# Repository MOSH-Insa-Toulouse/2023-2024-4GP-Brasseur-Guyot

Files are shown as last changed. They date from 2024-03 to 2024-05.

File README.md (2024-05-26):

# 2023-2024-4GP-Brasseur-Guyot

Projet capteur low-tech en graphite par Damien Brasseur et Tristan Guyot : le **BG0524-LTG**

### Contexte

Ce capteur a été réalisé, instrumenté et caractérisé dans le cadre d'un projet de 4ème année au département du Génie Physique de l'INSA TOULOUSE, encadré par Jérémie Grisolia, Benjamin Mestre, Arnaud Biganzoli et Cathy Crouzet. Tout le code, schématiques et mesures sont *open source* et réutilisables à volonté.

### Contacts

Damien : brasseu@insa-toulouse.fr <br>
Tristan : tguyot@insa-toulouse.fr

### Table des matières

[Description générale du projet](#coo) <br>
[Caractéristiques techniques](#zozo) <br>
[Mode d'emploi](#pookie) <br>
[Tests du capteur graphite](#booboo)

## 1 - Description générale du projet <a name="coo">

### Principe

Les capteurs sont partout. Dès qu’on cherche à automatiser un système, quel qu’il soit, on a besoin de capteurs. Pourtant, la plupart sont très coûteux en énergie, et leur multiplication fait qu’ils sont de plus en plus impactants sur l’environnement. C’est pour ça que les capteurs low-tech représentent un atout non négligeable. 

Un dépôt de graphite sur du papier forme un système granulaire, composé de grains de plus ou moins grande taille espacés d'une certaine distance, appelée distance inter-grain.
Cette propriété fait que sa conductance dépend de façon exponentielle de la distance inter-grain, qui peut être modulée en repliant le papier.
Ainsi, on peut retrouver la contrainte appliquée au matériau directement en mesurant la résistance aux bornes du capteur.

### Contenu du banc

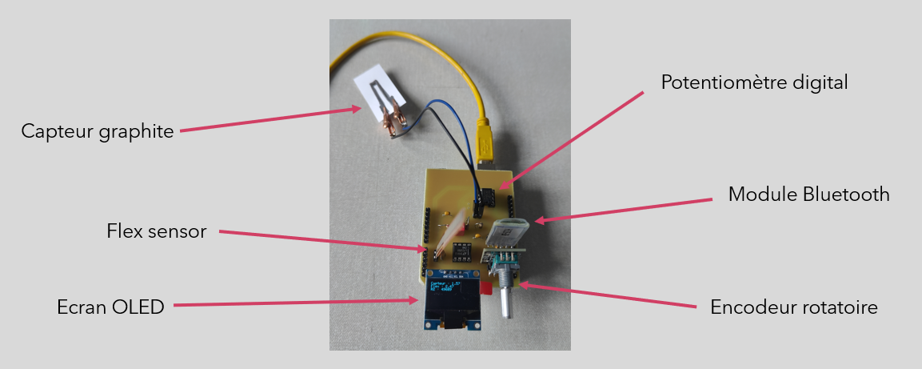
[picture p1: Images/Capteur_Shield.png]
Le projet dans son ensemble
 <br>

 - Le capteur graphite (interchangeable)
 - Un amplificateur permettant de mesurer avec précision les variations (cette amplification peut être modulée via la modification de la résistance R2 de la boucle de rétroaction de l'amplificateur, pilotée grâce à l'encodeur rotatoire)
 - Un capteur flex-sensor permettant de comparer les mesures du capteur graphite
 - Un écran OLED, sur lequel les mesures sont affichées en temps-réel
 - Une application Android, connectée en Bluetooth, sur laquelle les mesures et leur variation peuvent être visionnée

## 2 - Caractéristiques techniques <a name="zozo">

La *datasheet* est accessible [ici](./Datasheet/datasheet_capteur-graphite_final.pdf)

### Capteur

Le capteur est constitué d'une feuille de papier recouverte de graphite déposé au crayon selon un patterne spécifique :

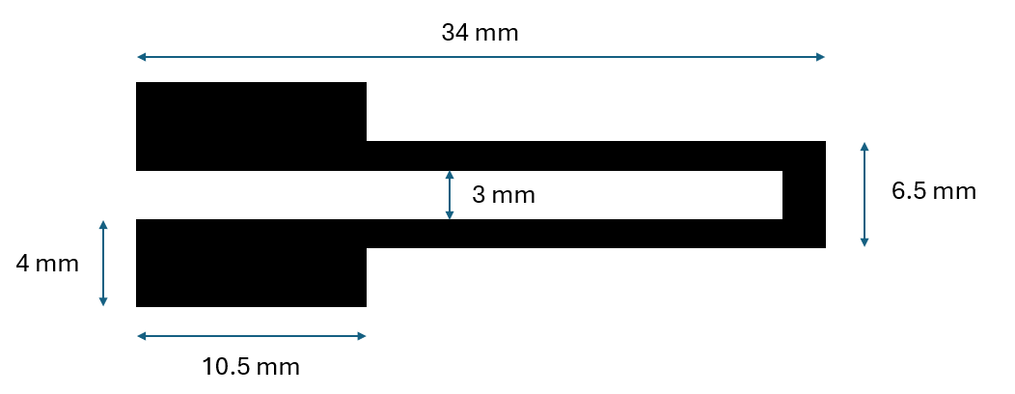
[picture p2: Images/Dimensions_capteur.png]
Le capteur graphite
 <br>

L'épaisseur du papier utilisé est de 200 µm.

### Electronique

L'électronique analogique permettant d'amplifier et de filtrer le signal du capteur graphite est composé d'un amplificateur transimpédance LTC1050 et de trois filtres :
 - Un filtre passif en entrée permettant d'éviter la distortion dans l'étage d'entrée
 - Un filtre actif basé sur l'amplificateur permettant une efficacité maximale
 - Un filtre passif en sortie pour éliminer le bruit introduit lors du traitement.

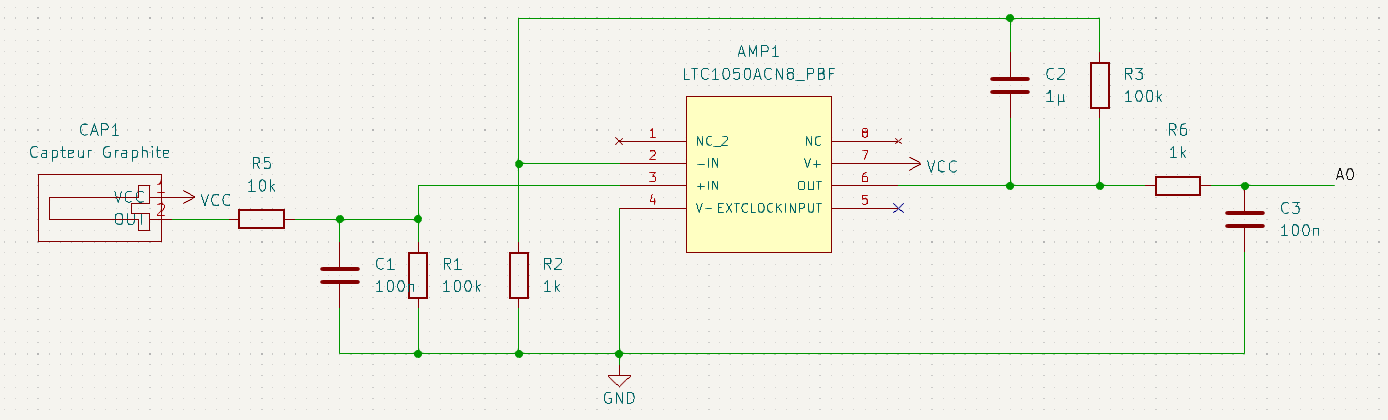
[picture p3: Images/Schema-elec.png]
Schéma de l'amplification
 <br>

### KiCad

Explications disponibles [ici](https://github.com/MOSH-Insa-Toulouse/2023-2024-4GP-Brasseur-Guyot/tree/main/KiCad)

### Code Arduino

Explications disponibles [ici](https://github.com/MOSH-Insa-Toulouse/2023-2024-4GP-Brasseur-Guyot/tree/main/Code%20Arduino)

### Application Android

Explications disponibles [ici](https://github.com/MOSH-Insa-Toulouse/2023-2024-4GP-Brasseur-Guyot/tree/main/Application%20Android)

## 3 - Mode d'emploi <a name="pookie">

### KiCad

Le dossier KiCad est à télécharger dans son intégralité.
Une fois téléchargé, il faudra recharger les librairies de symboles depuis le dossier Mods.

### Code Arduino

Pour charger le code sur la carte **Arduino UNO**, rien de plus facile ! Il suffit de l'ouvrir dans l'application Arduino IDE avec la carte branchée en USB, puis cliquer sur *Upload*.

### Application Android

L'application est à télécharger sur un téléphone Android. Après l'installation, aller dans les paramètres des applications Android et accorder l'accès au Bluetooth et au micro à l'application.
Pour assurer la connexion entre la carte Arduino et le téléphone, il faut d'abord se connecter au module Bluetooth de la carte avec l'interface générale Bluetooth du téléphone. Ensuite, on pourra sélectionner dans l'application le module et on pourra commencer à s'amuser.

## 4 - Tests du capteur graphite <a name="booboo">

Nous avons réalisé des mesures de compression et de détente avec des capteurs comportant différentes densités de graphite (variant avec le type de crayon : 4H, HB et 4B), ainsi que pour le Flex sensor.

Le banc de test sur lequel nous avons testé les mesures comporte 4 demi-cercles de diamètres 2cm, 3cm, 4cm et 5cm, respectivement. La déformation est calculée selon l'expression suivante : $\varepsilon = \frac{D}{e}$ avec $D$ diamètre du demi-cercle et $e$ épaisseur du papier.

Voici la caractéristique en détente : 

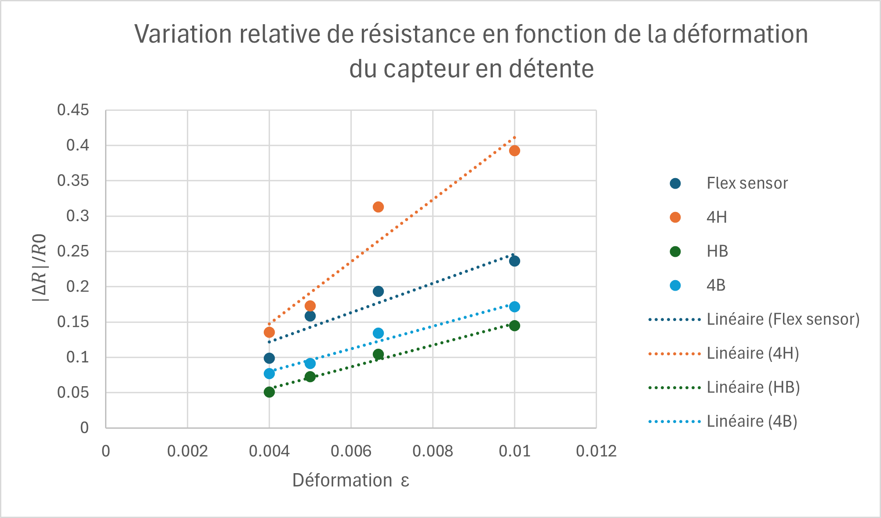
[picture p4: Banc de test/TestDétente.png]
Caractéristique en détente
 <br>

On remarque que la variation de résistance la plus marquée (pente la plus élevée) est cele du capteur au crayon 4H. De façon surprenante, le capteur au cayon HB est moins efficace que le capteur 4B.

Voici la caractéristique en compression : 

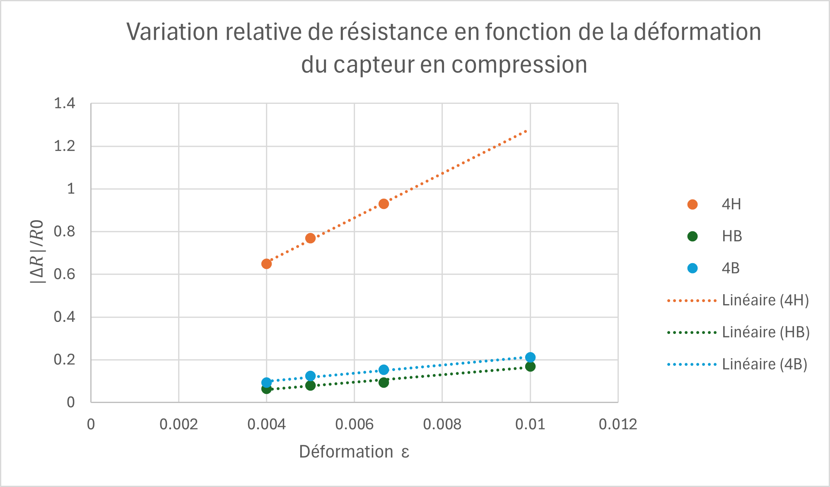
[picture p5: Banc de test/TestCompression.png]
Caractéristique en compression
 <br>

Même comportement, sauf qu'une limite a été atteinte en mesure de compression (demi-cercle de 2cm) avec le capteur 4H. Le flex sensor ne fonctionnant que dans un seul sens, nous n'avons pas pu le tester dans ces conditions.

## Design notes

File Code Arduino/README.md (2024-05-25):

# Code Arduino

Ce code permet de réaliser l'interface entre les capteurs, le potentiomètre permettant de régler l'amplification, l'écran OLED et la connexion Bluetooth au téléphone.

Boucle de 50ms : 
 - Récupération des valeurs analogiques de tension du capteur graphite et du flex sensor
 - Réglage de la résistance R2 de l'amplification avec l'encodeur rotatoire
 - Affichage des valeurs de tension sur l'écran OLED
 - Envoi des valeurs de tension au module Bluetooth (1 fois sur 10 => toutes les 500ms)

### capteur_graphite.ino

C'est le code à envoyer sur la carte Arduino UNO pour faire fonctionner le banc.

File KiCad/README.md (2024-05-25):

# Shield KiCad

Modèle du PCB par lequel les différents éléments du projet sont reliés, réalisé sur **KiCad** :

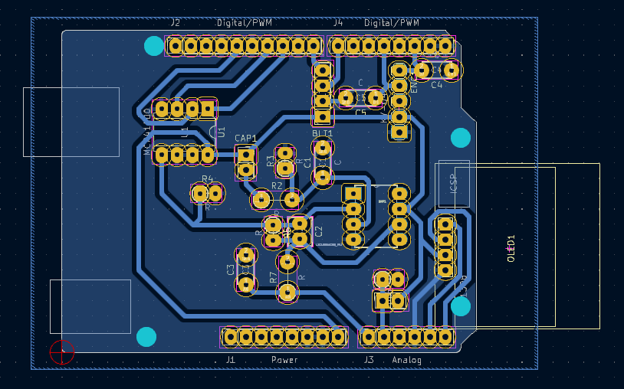
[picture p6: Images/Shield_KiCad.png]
Shield KiCad
 <br>

Principales caractéristiques :
 - Tous les circuits sur une seule face
 - Tous les composants directement intégrés au PCB
 - Pins non reliés : au GND

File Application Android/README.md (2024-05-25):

# Application Android

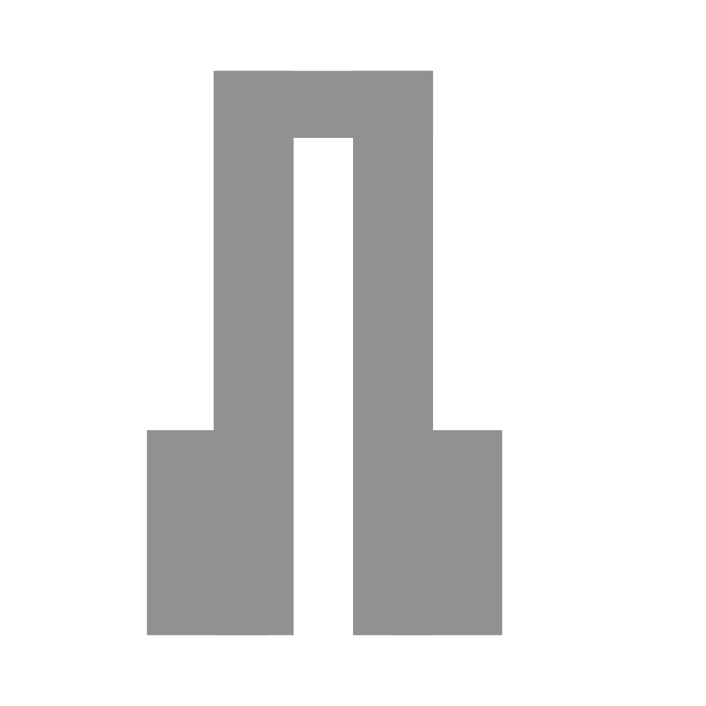
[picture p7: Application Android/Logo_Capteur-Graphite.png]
Logo App Capteur
 <br>

## Description de l'application

Cette application, réalisée à l'aide du MIT App Inventor, permet de se connecter en Bluetooth à la carte Arduino faisant tourner le capteur, et récupérer les mesures à la fois du capteur graphite et du flex sensor. 
Ensuite, un graphe permet de visualiser la variation en temps-réel de ces mesures, soit simultanément ou séparément.

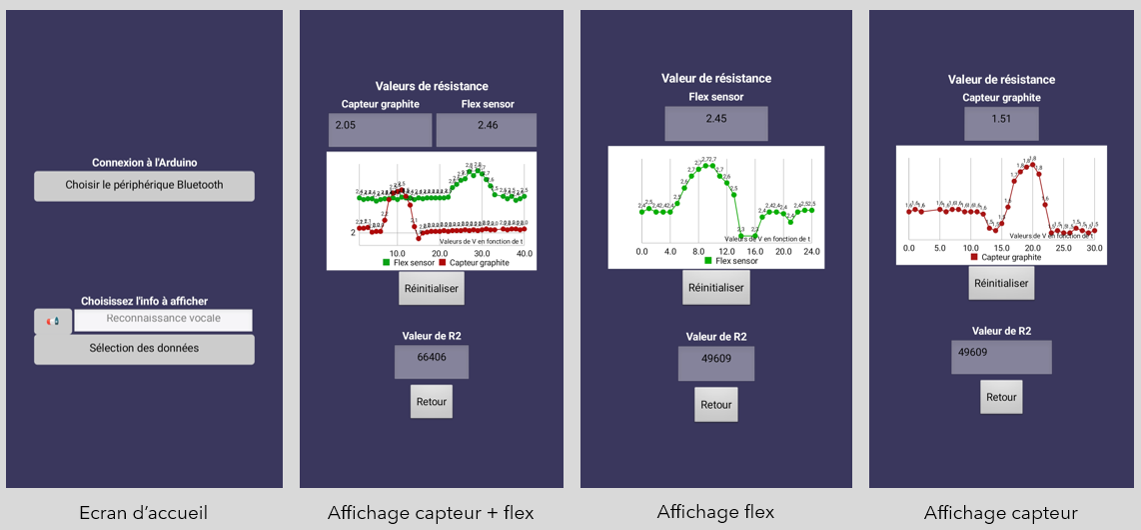
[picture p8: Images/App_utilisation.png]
Différents écrans de l'application
 <br>

Les informations sont envoyées par l’Arduino via Bluetooth sous forme de chaîne de caractères toutes les 500ms. 
L’application s’occupe de séparer les chaînes, de répartir les informations et d’afficher les données correctes au bon endroit.

### Version 0.1.1

Corrigé la reconnaissance vocale, et les erreurs d'affichages des mesures

### Version 0.2

Ajout des graphiques de suivi des valeurs

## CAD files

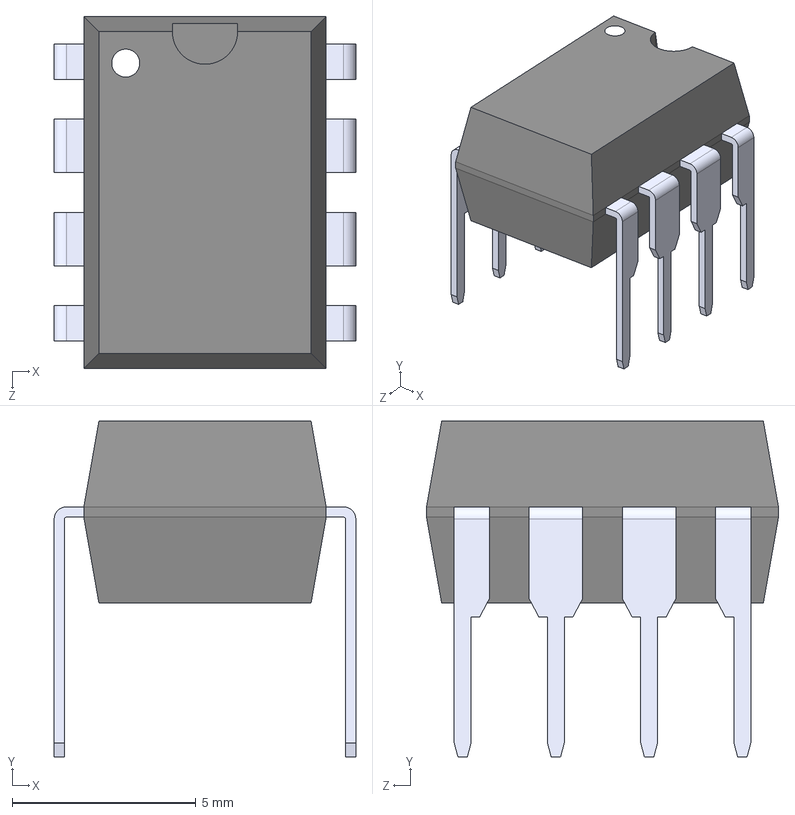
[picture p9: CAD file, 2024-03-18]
KiCad/Mods/LTC1050ACN8_PBF.step
8.22 x 9.14 x 9.59 mm

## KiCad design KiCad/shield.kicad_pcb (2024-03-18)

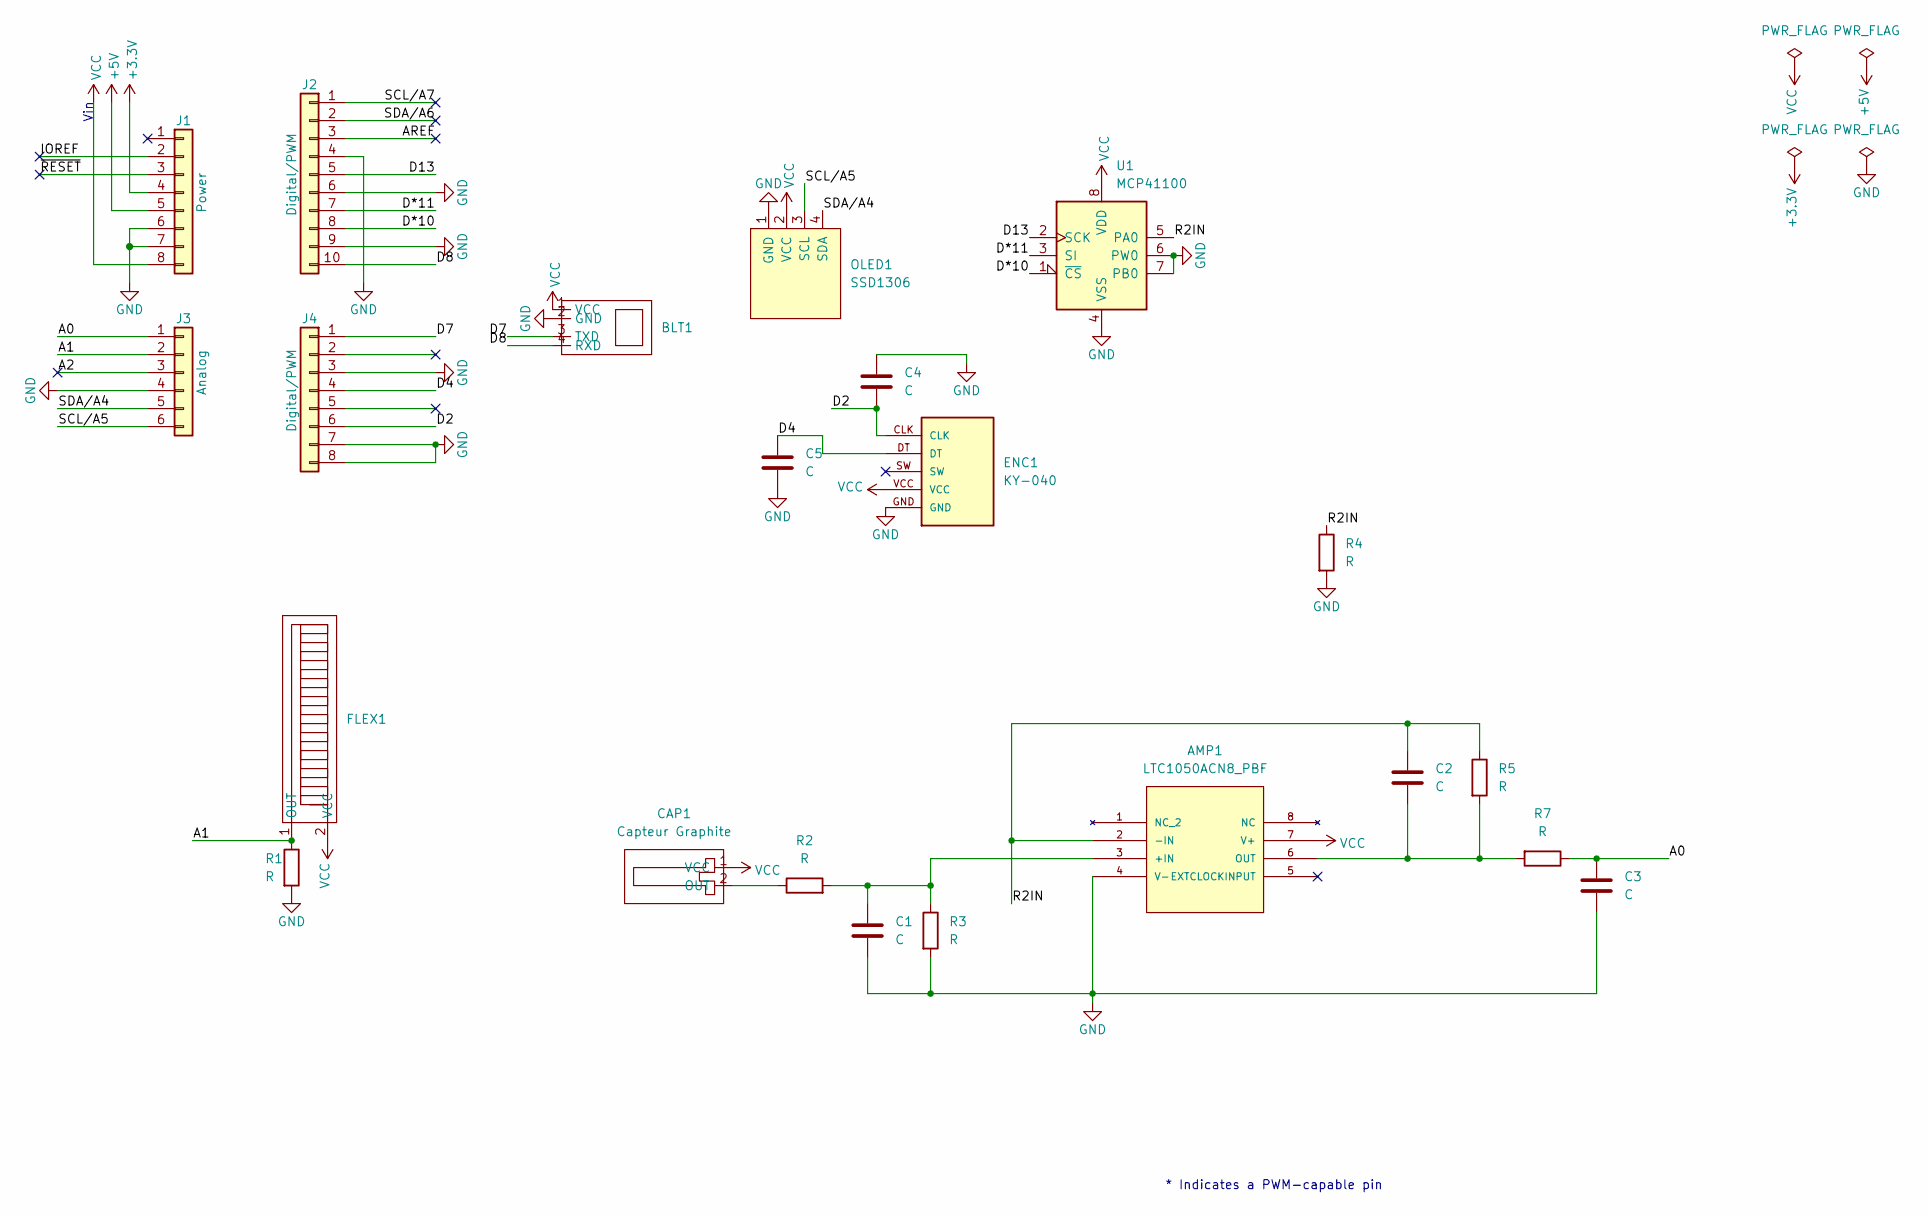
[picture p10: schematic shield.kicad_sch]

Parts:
AMP1: LTC1050ACN8_PBF; PDIP-8_N; MANUFACTURER_PART_NUMBER ltc1050acn8
BLT1: PinSocket_1x04_P2.54mm_Vertical
C1, C3, C4, C5: C; C_Disc_D4.7mm_W2.5mm_P5.00mm
C2: C; C_Rect_L4.6mm_W3.8mm_P2.50mm_MKS02_FKP02
CAP1: Capteur Graphite; PinSocket_1x02_P2.54mm_Vertical
ENC1: KY-040; KY-040-PORT
FLEX1: PinSocket_1x02_P2.54mm_Vertical
J1: Power; PinSocket_1x08_P2.54mm_Vertical
J2: Digital/PWM; PinSocket_1x10_P2.54mm_Vertical
J3: Analog; PinSocket_1x06_P2.54mm_Vertical
J4: Digital/PWM; PinSocket_1x08_P2.54mm_Vertical
OLED1: SSD1306; 128x64OLED
R1, R3, R4, R5: R; R_Axial_DIN0207_L6.3mm_D2.5mm_P2.54mm_Vertical
R2, R7: R; R_Axial_DIN0207_L6.3mm_D2.5mm_P5.08mm_Vertical
U1: MCP41100; DIP-8_W7.62mm_LongPads

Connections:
+3V3: J1.4
+5V: J1.5
/A0: C3.1, J3.1, R7.1
/A1: FLEX1.1 (OUT), J3.2, R1.1
/A2: J3.3
/AREF: J2.3
/D2: C4.2, ENC1.CLK, J4.6
/D4: C5.1, ENC1.DT, J4.4
/D7: BLT1.3 (TXD), J4.1
/D8: BLT1.4 (RXD), J2.10
/D13: J2.5, U1.2 (SCK)
/D*10: J2.8, U1.1 (~CS)
/D*11: J2.7, U1.3 (SI)
/IOREF: J1.2
/R2IN: AMP1.2 (-IN), C2.1, R4.1, R5.1, U1.5 (PA0)
/SCL/A5: J3.6, OLED1.3 (SCL)
/SCL/A7: J2.1
/SDA/A4: J3.5, OLED1.4 (SDA)
/SDA/A6: J2.2
/~RESET: J1.3
GND: AMP1.4 (V-), BLT1.2 (GND), C1.2, C3.2, C4.1, C5.2, ENC1.GND, J1.6, J1.7, J2.4, J2.6, J2.9, J3.4, J4.3, J4.7, J4.8, OLED1.1 (GND), R1.2, R3.2, R4.2, U1.4 (VSS), U1.6 (PW0), U1.7 (PB0)
unnamed: AMP1.3 (+IN), C1.1, R2.2, R3.1
unnamed: AMP1.6 (OUT), C2.2, R5.2, R7.2
unnamed: CAP1.2 (OUT), R2.1
VCC: AMP1.7 (V+), BLT1.1 (VCC), CAP1.1 (VCC), ENC1.VCC, FLEX1.2 (VCC), J1.8, OLED1.2 (VCC), U1.8 (VDD)

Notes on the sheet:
* Indicates a PWM-capable pin
Vin

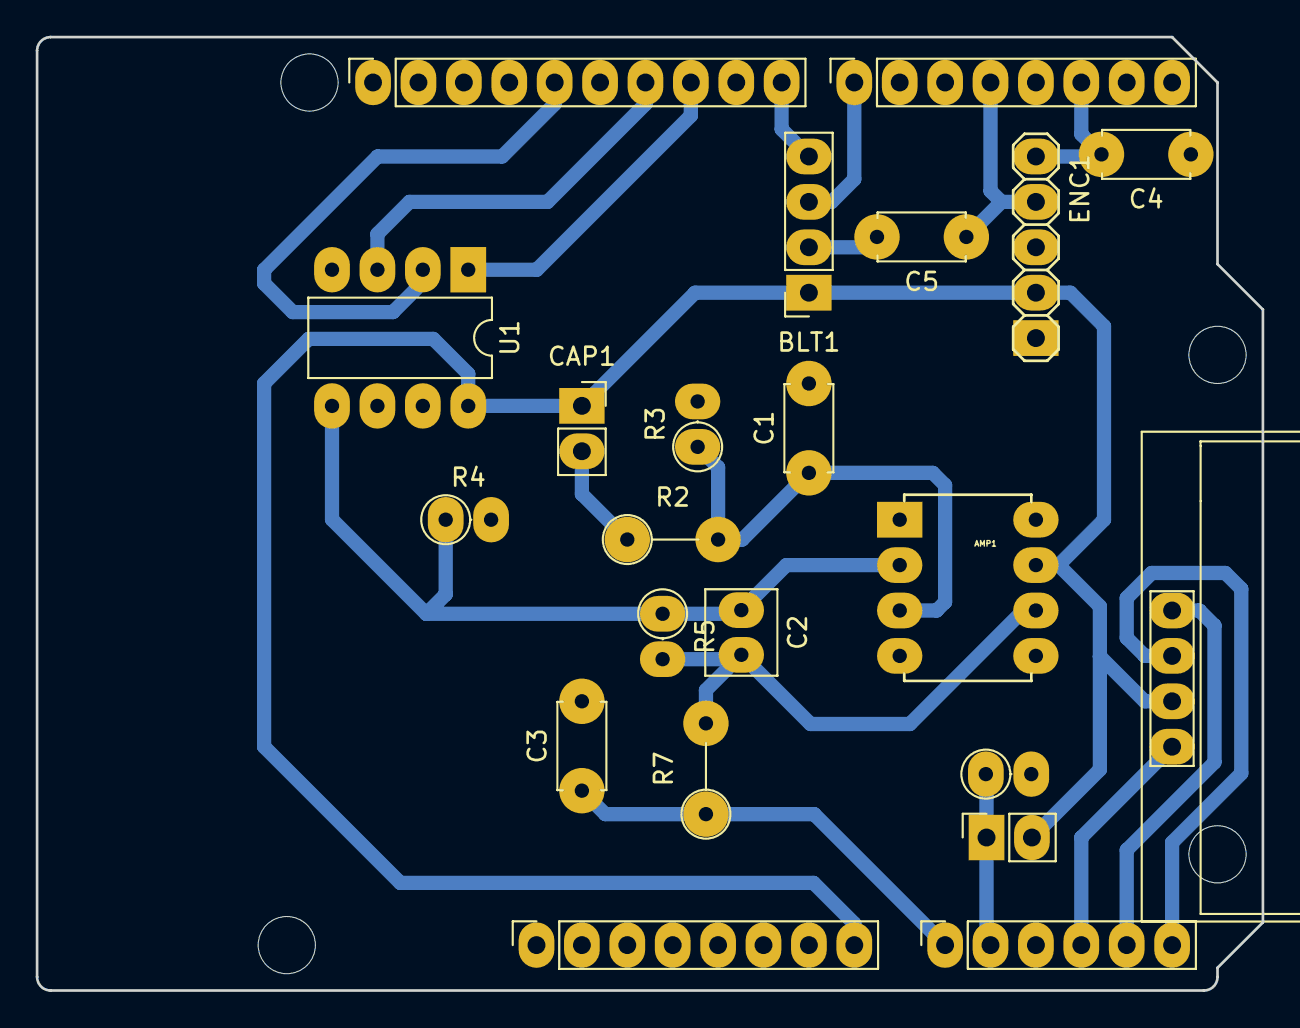
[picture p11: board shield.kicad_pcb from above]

Board: 2 copper layers, 68.6 x 53.3 mm, 26 parts (0 on the bottom side), 17 nets.

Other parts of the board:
MH1, MH2, MH3, MH4: MountingHole_3.2mm

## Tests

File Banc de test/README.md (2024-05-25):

Fichiers de la caractérisation expérimentale avec le banc de test

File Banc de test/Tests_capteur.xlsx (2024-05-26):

 |  |  | Flex |  |  | 4H |  |  | HB |  |  | 4B
 | d | ε | V0 | V | Diff | V0 | V | Diff | V0 | V | Diff | V0 | V | Diff | e(papier)
Flexion | 5 | 0.004 | 2.33 | 2.1 | 0.09871244635 | 2.14 | 1.85 | 0.1355140187 | 3.16 | 3 | 0.05063291139 | 3.5 | 3.23 | 0.07714285714 | 0.02
 | 4 | 0.005 | 2.33 | 1.96 | 0.1587982833 | 2.14 | 1.77 | 0.1728971963 | 3.16 | 2.93 | 0.07278481013 | 3.5 | 3.18 | 0.09142857143
 | 3 | 0.006666666667 | 2.33 | 1.88 | 0.1931330472 | 2.14 | 1.47 | 0.3130841121 | 3.16 | 2.83 | 0.1044303797 | 3.5 | 3.03 | 0.1342857143
 | 2 | 0.01 | 2.33 | 1.78 | 0.2360515021 | 2.14 | 1.3 | 0.3925233645 | 3.18 | 2.72 | 0.1446540881 | 3.5 | 2.9 | 0.1714285714
Compression | 5 | 0.004 |  |  |  | 2 | 3.3 | 0.65 | 3.1 | 3.3 | 0.06451612903 | 3.2 | 3.5 | 0.09375
 | 4 | 0.005 |  |  |  | 2 | 3.54 | 0.77 | 3.1 | 3.35 | 0.08064516129 | 3.2 | 3.6 | 0.125
 | 3 | 0.006666666667 |  |  |  | 2 | 3.86 | 0.93 | 2.88 | 3.15 | 0.09375 | 3.2 | 3.69 | 0.153125
 | 2 | 0.01 |  |  |  | - | - |  | 2.6 | 3.04 | 0.1692307692 | 3.3 | 4 | 0.2121212121

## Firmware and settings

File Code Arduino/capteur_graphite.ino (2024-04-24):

#include <SoftwareSerial.h>
#include <SPI.h>
#include <Adafruit_SSD1306.h>


// Bluetooth

#define rxPin 7
#define txPin 8
#define baudrate 9600
SoftwareSerial mySerial(rxPin, txPin);

int i = 0;

// Digital potentiometre

#define MCP_NOP 0b00000000
#define MCP_WRITE 0b00010001
#define MCP_SHTDWN 0b00100001

const int ssMCPin = 10;

void SPIWrite(uint8_t cmd, uint8_t data, uint8_t ssPin) // SPI write the command and data to the MCP IC connected to the ssPin
{
  SPI.beginTransaction(SPISettings(14000000, MSBFIRST, SPI_MODE0)); //https://www.arduino.cc/en/Reference/SPISettings
  
  digitalWrite(ssPin, LOW); // SS pin low to select chip
  
  SPI.transfer(cmd);        // Send command code
  SPI.transfer(data);       // Send associated value
  
  digitalWrite(ssPin, HIGH);// SS pin high to de-select chip
  SPI.endTransaction();
}

int resInit = 127;

// OLED screen

#define nombreDePixelsEnLargeur 128         // Taille de l'écran OLED, en pixel, au niveau de sa largeur
#define nombreDePixelsEnHauteur 64          // Taille de l'écran OLED, en pixel, au niveau de sa hauteur
#define brocheResetOLED         -1          // Reset de l'OLED partagé avec l'Arduino (d'où la valeur à -1, et non un numéro de pin)
#define adresseI2CecranOLED     0x3C        // Adresse de "mon" écran OLED sur le bus i2c (généralement égal à 0x3C ou 0x3D)

Adafruit_SSD1306 ecranOLED(nombreDePixelsEnLargeur, nombreDePixelsEnHauteur, &Wire, brocheResetOLED);

// encoder 

#define encoder0PinA  2  //CLK Output A Do not use other pin for clock as we are using interrupt
#define encoder0PinB  4  //DT Output B

volatile unsigned int encoder0Pos = 0;

void doEncoder() {
  if (digitalRead(encoder0PinB)==HIGH) {
    encoder0Pos++;
  } else {
    encoder0Pos--;
  }
}

int encoderState;

void setup() {
  // def pins Bluetooth
  pinMode(rxPin, INPUT);
  pinMode(txPin, OUTPUT);

  Serial.begin(9600);
  mySerial.begin(9600);
  
  // def pins sensors
  pinMode(A0, INPUT);
  pinMode(A1, INPUT);

  // def pins Digipot
  pinMode (ssMCPin, OUTPUT); //select pin output
  digitalWrite(ssMCPin, HIGH); //SPI chip disabled
  SPI.begin();
  SPIWrite(MCP_WRITE, resInit, ssMCPin);

  // OLED screen init
  if(!ecranOLED.begin(SSD1306_SWITCHCAPVCC, adresseI2CecranOLED))
  {
    while(1);
  }                               // Arrêt du programme (boucle infinie) si échec d'initialisation

  ecranOLED.clearDisplay();                   // Effaçage de l'intégralité du buffer
  ecranOLED.setTextSize(1);                   // Taille des caractères
  ecranOLED.setCursor(0, 0);

  for(byte numeroDeLigne=1; numeroDeLigne<=8; numeroDeLigne++) {
      ecranOLED.setTextColor(SSD1306_WHITE);                  // Affichage du texte en "blanc" (avec la couleur principale, en fait, car l'écran monochrome peut être coloré)
      ecranOLED.print("coucou ");
  }
  ecranOLED.display();

  //def pins encoder
  pinMode(encoder0PinA, INPUT); 
  digitalWrite(encoder0PinA, HIGH);       // turn on pullup resistor

  pinMode(encoder0PinB, INPUT); 
  digitalWrite(encoder0PinB, HIGH);       // turn on pullup resistor

  attachInterrupt(0, doEncoder, RISING); // encoder pin on interrupt 0 - pin2

}

void loop() 
{   
  // main code

  float valCap;
  float valFlex;

  int resDigipot;

  String fullString;

  valCap = analogRead(A0)*5.0/1024;
  valFlex = analogRead(A1)*5.0/1024;
  
  encoderState = encoder0Pos;

  if (encoderState >= 128)
  {
    encoder0Pos = 127;
    encoderState = 127;
  }
  if (encoderState <= -127)
  {
    encoder0Pos = -126;
    encoderState = -126;
  }  
  
  SPIWrite(MCP_WRITE, encoderState + 127, ssMCPin);

  resDigipot = 50000 - 50000*(encoderState + 127)/256;
  

  // Bluetooth display
  i++;
  if (i == 10) i = 0;
  if(i==9) {
    fullString += String(valCap);
    fullString += ";";
    fullString += String(valFlex);
    fullString += ";";
    fullString += String(resDigipot);
    fullString += ";";
    mySerial.println(fullString);
  }


  // screen display
  ecranOLED.clearDisplay();
  ecranOLED.setTextSize(1);
  ecranOLED.setCursor(0, 0);
  ecranOLED.print("Capteur : ");
  ecranOLED.println(valCap);
  ecranOLED.print("Flex : ");
  ecranOLED.println(valFlex);
  ecranOLED.print("R2 : ");
  ecranOLED.println(resDigipot);
  ecranOLED.display();
  
  delay(50);
}

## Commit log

2024-03-18 Ajout du kicad du shield
    Penser à recharger les librairies de symboles après téléchargement
    [LTC1050ACN8_PBF.step, shield.kicad_pcb, shield.kicad_sch]
2024-03-18 Changement de nom
    [LTC1050ACN8_PBF.step, shield.kicad_pcb, shield.kicad_sch]
2024-05-25 Added test bench
    [Tests_capteur.xlsx]

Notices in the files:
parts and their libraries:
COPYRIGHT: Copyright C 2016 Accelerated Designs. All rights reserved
